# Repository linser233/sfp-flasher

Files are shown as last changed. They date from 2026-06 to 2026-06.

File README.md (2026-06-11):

# SFP_FLASHER

SFP/QSFP Flash Tool

QSFP-DD Pinout
| Pin | Symbol | Description |
|-----|---|---|
| 1 | GND | Ground |
| 2 | Tx2n | Transmitter Inverted Data Input |
| 3 | Tx2p | Transmitter Non-Inverted Data Input  |
| 4 | GND | Ground |
| 5 | Tx4n | Transmitter Inverted Data Input |
| 6 | Tx4p | Transmitter Non-Inverted Data Input  |
| 7 | GND | Ground |
| 8 | ModSelL  | Module Select |
| 9 | ResetL | Module Reset |
| 10  | Vcc Rx | +3.3V Power Supply Receiver |
| 11  | SCL | 2-wire Serial Interface Clock |
| 12  | SDA | 2-wire Serial Interface Data |
| 13  | GND | GND |
| 14  | Rx3p | Receiver Non-Inverted Data Output |
| 15  | Rx3n | Receiver Inverted Data Output |
| 16  | GND | Ground |
| 17  | Rx1p | Receiver Non-Inverted Data Output |
| 18  | Rx1n | Receiver Inverted Data Output |
| 19  | GND | Ground |
| 20  | GND | Ground |
| 21  | Rx2n | Receiver Inverted Data Output |
| 22  | Rx2p | Receiver Non-Inverted Data Output |
| 23  | GND | Grounds |
| 24  | Rx4n | Receiver Inverted Data Output |
| 25  | Rx4p | Receiver Non-Inverted Data Output |
| 26  | GND | Ground |
| 27  | ModPrsL  | Module Present |
| 28  | IntL | Interrupt |
| 29  | Vcc Tx | +3.3V Power Supply Transmitter |
| 30  | Vcc1 | +3.3V Power Supply |
| 31  | LPMode | Low Power Mode |
| 32  | GND | Ground |
| 33  | Tx3p | Transmitter Non-Inverted Data Input  |
| 34  | Tx3n | Transmitter Inverted Data Input |
| 35  | GND | Ground |
| 36  | Tx1p | Transmitter Non-Inverted Data Input  |
| 37  | Tx1n | Transmitter Inverted Data Input |
| 38  | GND | Ground |
| 39  | GND | Ground |
| 40  | Tx6n | Transmitter Inverted Data Input |
| 41  | Tx6p | Transmitter Non-Inverted Data Input  |
| 42  | GND | Ground |
| 43  | Tx8n | Transmitter Inverted Data Input |
| 44  | Tx8p | Transmitter Non-Inverted Data Input  |
| 45  | GND | Ground |
| 46  | Reserved | For future use |
| 47  | VS1 | Module Vendor Specific 1 |
| 48  | VccRx1 | 3.3V Power Supply |
| 49  | VS2 | Module Vendor Specific 2 |
| 50  | VS3 | Module Vendor Specific 3 |
| 51  | GND | Ground |
| 52  | Rx7p | Receiver Non-Inverted Data Output |
| 53  | Rx7n | Receiver Inverted Data Output |
| 54  | GND | Ground |
| 55  | Rx5p | Receiver Non-Inverted Data Output |
| 56  | Rx5n | Receiver Inverted Data Output |
| 57  | GND | Ground |
| 58  | GND | Ground |
| 59  | Rx6n | Receiver Inverted Data Output |
| 60  | Rx6p | Receiver Non-Inverted Data Output |
| 61  | GND | Ground |
| 62  | Rx8n | Receiver Inverted Data Output |
| 63  | Rx8p | Receiver Non-Inverted Data Output |
| 64  | GND | Ground |
| 65  | NC | No Connect |
| 66  | Reserved | For future use |
| 67  | VccTx1 | 3.3V Power Supply |
| 68  | Vcc2 | 3.3V Power Supply |
| 69  | Reserved | For Future Use |
| 70  | GND | Ground |
| 71  | Tx7p | Transmitter Non-Inverted Data Input  |
| 72  | Tx7n | Transmitter Inverted Data Input |
| 73  | GND | Ground |
| 74  | Tx5p | Transmitter Non-Inverted Data Input  |
| 75  | Tx5n | Transmitter Inverted Data Input |
| 76  | GND | Ground |

Control Signals
| Name | Function | Description |
|---|---|---|
| ModPrsL | Output, asserted low | Pull-up by host when no transceiver/cable is present. Connected to ground inside the transceiver. Hence, asserted low when a transceiver/cable is plugged in. |
| ModSelL | Input, asserted Low  | Module Select input pin, terminated high in the module. Only when held low by the host, the module responds to 2-wire serial communication commands. Enables multiple modules to share a single 2-wire bus. |
| ResetL  | Input, asserted Low  | Reset input pin, pulled high in the module. A low level on the ResetL pin for longer than the minimum length initiates a module reset. When de-asserted the transceiver starts initialization. |
| LPMode  | Input, asserted high | Low Power Mode input, pulled up inside the module. Hardware control signal for forcing the transceiver into low-power state. Can be overwritten by low-power mode command. |
| ePPS | Input | Not implemented |
| IntL | Output, asserted low | Interrupt Low is an open-collector output, terminated high in the host system. A “Low” indicates a possible module operational fault or a status critical to the host system, e.g. temperature alarm. |

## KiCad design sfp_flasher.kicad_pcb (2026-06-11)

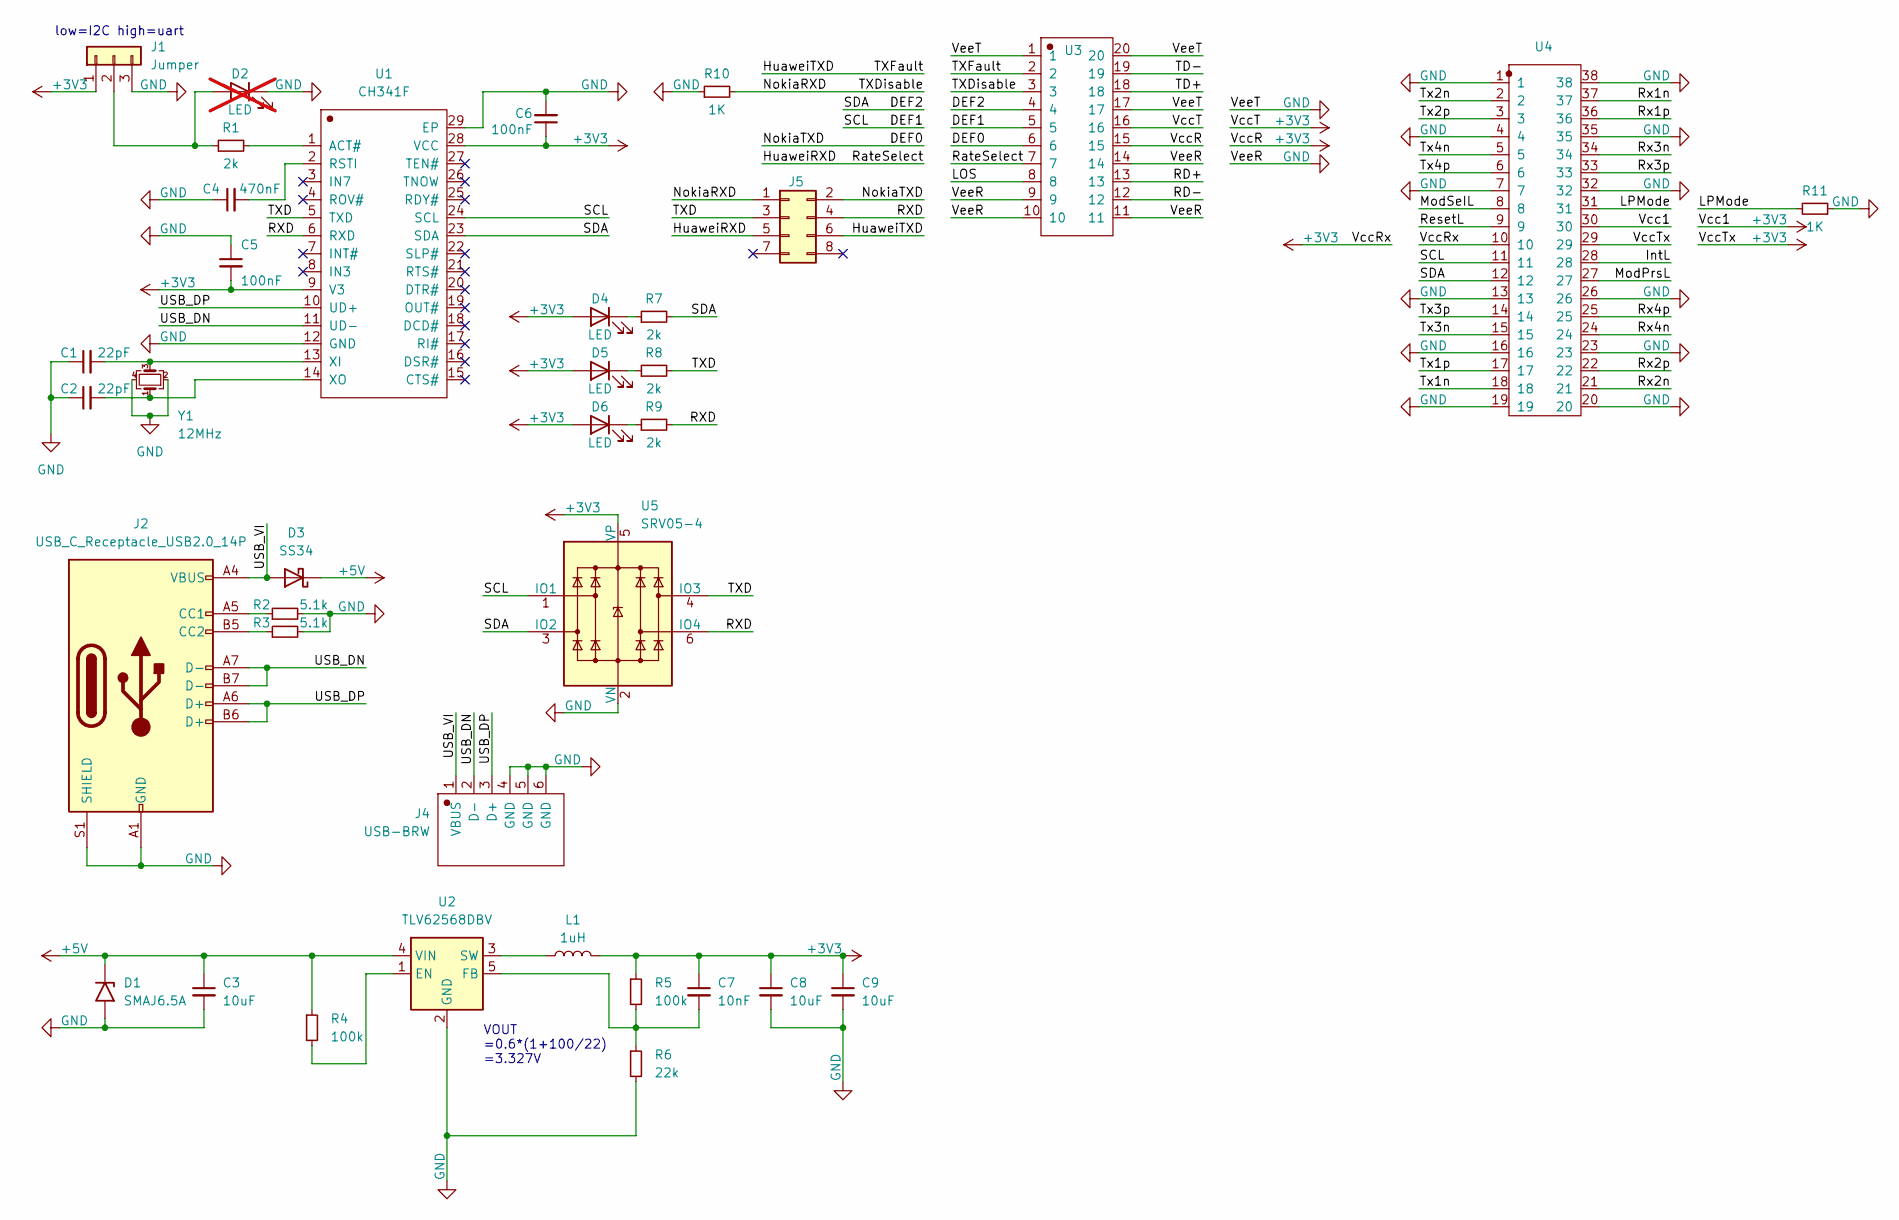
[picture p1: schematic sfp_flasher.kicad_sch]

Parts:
C1, C2: 22pF; C_0603_1608Metric; LCSC C1555
C3, C8, C9: 10uF; C_0805_2012Metric
C4: 470nF; C_0603_1608Metric
C5, C6: 100nF; C_0603_1608Metric; LCSC C1525
C7: 10nF; C_0603_1608Metric
D1: SMAJ6.5A; D_SMA
D2: LED; LED_0603_1608Metric; not fitted
D3: SS34; D_SMA
D4: LED; LED_D3.0mm
D5, D6: LED; LED_0603_1608Metric
J1: Jumper; PinHeader_1x03_P2.54mm_Vertical
J2: USB_C_Receptacle_USB2.0_14P; USB_C_Receptacle_Palconn_UTC16-G
J4: USB-BRW; USB_B_OST_USB-B1HSxx_Horizontal
J5: uart; PinHeader_2x04_P2.54mm_Vertical
L1: 1uH; L_1008_2520Metric
R1, R7, R8, R9: 2k; R_0603_1608Metric; LCSC C11702
R2, R3: 5.1k; R_0603_1608Metric; LCSC C11702
R4, R5: 100k; R_0603_1608Metric; LCSC C11702
R6: 22k; R_0603_1608Metric; LCSC C11702
R10, R11: 1K; R_0603_1608Metric; LCSC C11702
U1: CH341F; QFN-28_L4.0-W4.0-P0.40-BL-EP
U2: TLV62568DBV; SOT-23-5
U3: XDSFP-020-0852; CONN-SMD_20P-P0.80-H_M42F-08P-020-P002G
U4: UMAX952L0301; CONN-SMD_UMAX952L0301
U5: SRV05-4; SOT-23-6
Y1: 12MHz; Crystal_SMD_SeikoEpson_TSX3225-4Pin_3.2x2.5mm; LCSC C9002

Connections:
+3V3: C5.2, C6.1, C7.1, C8.1, C9.1, D4.2 (A), D5.2 (A), D6.2 (A), J1.1, L1.2, R5.1, U1.9 (V3), U1.28 (VCC), U3.15, U3.16, U4.10, U4.29, U4.30, U5.5 (VP)
+5V: C3.1, D1.1 (A1), D3.1 (K), R4.1, U2.4 (VIN)
/DEF0: J5.2, U3.6
/DEF1: U1.24 (SCL), U3.5, U4.11, U5.1 (IO1)
/DEF2: R7.2, U1.23 (SDA), U3.4, U4.12, U5.3 (IO2)
/HuaweiRXD: J5.5, U3.7
/HuaweiTXD: J5.6, U3.2
/IntL: U4.28
/LOS: U3.8
/LPMode: R11.2, U4.31
/ModPrsL: U4.27
/ModSeIL: U4.8
/NokiaRXD: J5.1, R10.2, U3.3
/RD+: U3.13
/RD-: U3.12
/RXD: J5.4, R9.2, U1.6 (RXD), U5.6 (IO4)
/ResetL: U4.9
/Rx1n: U4.37
/Rx1p: U4.36
/Rx2n: U4.21
/Rx2p: U4.22
/Rx3n: U4.34
/Rx3p: U4.33
/Rx4n: U4.24
/Rx4p: U4.25
/TD+: U3.18
/TD-: U3.19
/TXD: J5.3, R8.2, U1.5 (TXD), U5.4 (IO3)
/Tx1n: U4.18
/Tx1p: U4.17
/Tx2n: U4.2
/Tx2p: U4.3
/Tx3n: U4.15
/Tx3p: U4.14
/Tx4n: U4.5
/Tx4p: U4.6
/USB_DN: J2.A7 (D-), J2.B7 (D-), J4.2 (D-), U1.11 (UD-)
/USB_DP: J2.A6 (D+), J2.B6 (D+), J4.3 (D+), U1.10 (UD+)
/USB_VI: D3.2 (A), J2.A4 (VBUS), J2.A9 (VBUS), J2.B4 (VBUS), J2.B9 (VBUS), J4.1 (VBUS)
GND: C1.1, C2.1, C3.2, C4.1, C5.1, C6.2, C8.2, C9.2, D1.2 (A2), D2.1 (K), J1.3, J2.A1 (GND), J2.A12 (GND), J2.B1 (GND), J2.B12 (GND), J2.S1 (SHIELD), J4.4 (GND), J4.5 (GND), J4.6 (GND), R2.2, R3.2, R6.2, R10.1, R11.1, U1.12 (GND), U1.29 (EP), U2.2 (GND), U3.1, U3.9, U3.10, U3.11, U3.14, U3.17, U3.20, U4.1, U4.4, U4.7, U4.13, U4.16, U4.19, U4.20, U4.23, U4.26, U4.32, U4.35, U4.38, U5.2 (VN), Y1.2, Y1.4
unnamed: D2.2 (A), J1.2, R1.1
unnamed: D4.1 (K), R7.1
unnamed: D5.1 (K), R8.1
unnamed: D6.1 (K), R9.1
unnamed: J2.A5 (CC1), R2.1
unnamed: J2.B5 (CC2), R3.1
unnamed: R1.2, U1.1 (ACT#)
unnamed: C4.2, U1.2 (RSTI)
unnamed: C1.2, U1.13 (XI), Y1.3
unnamed: C2.2, U1.14 (XO), Y1.1
unnamed: R4.2, U2.1 (EN)
unnamed: C7.2, R5.2, R6.1, U2.5 (FB)
unnamed: L1.1, U2.3 (SW)

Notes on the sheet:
VOUT =0.6*(1+100/22) =3.327V
low=I2C high=uart

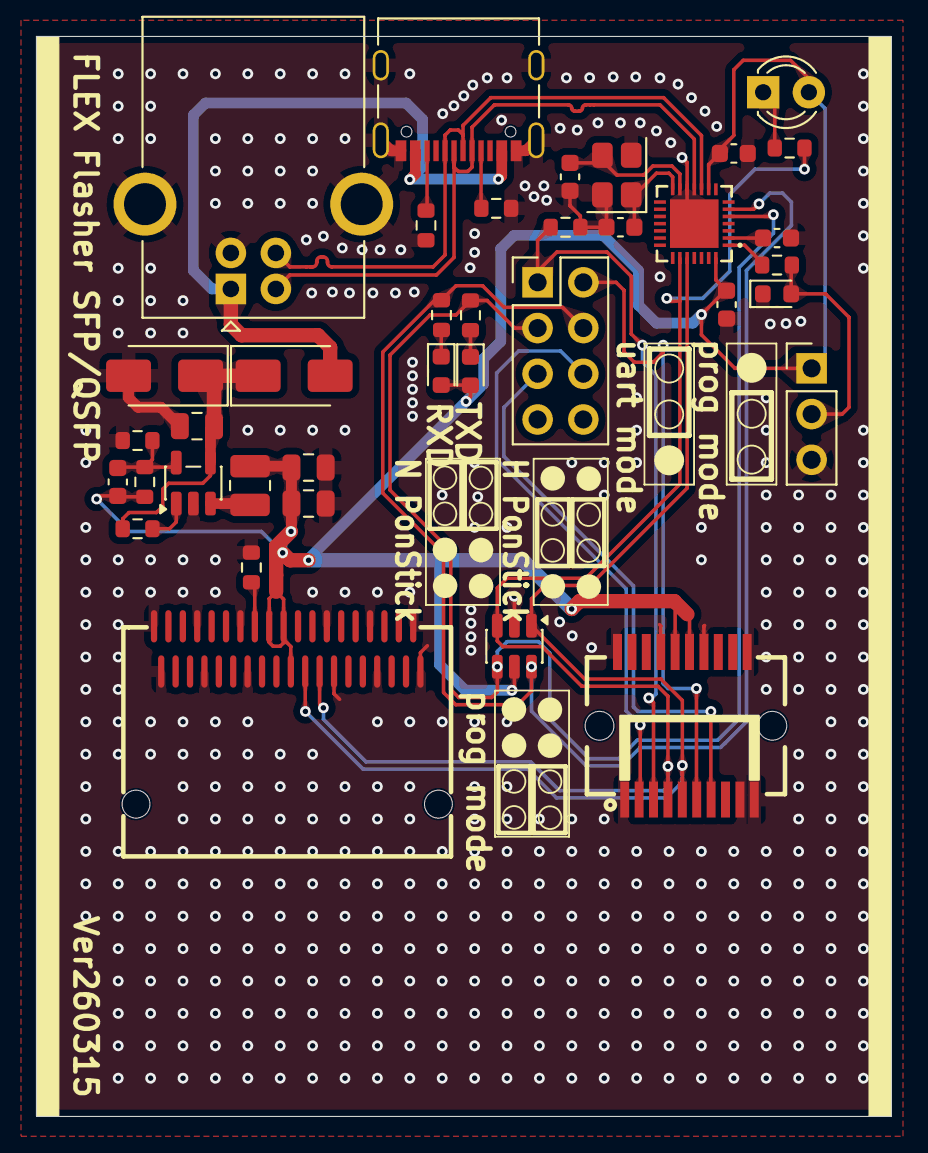
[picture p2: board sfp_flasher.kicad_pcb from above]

Board: 2 copper layers, 47.5 x 60.0 mm, 37 parts (0 on the bottom side), 28 nets.
